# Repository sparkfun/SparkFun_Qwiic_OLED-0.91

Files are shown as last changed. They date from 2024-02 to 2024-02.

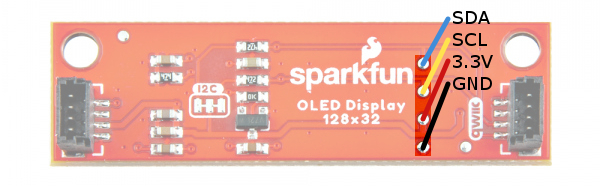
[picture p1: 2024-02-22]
docs/assets/img/LCD-24606-Qwiic-OLED-Display-Back_I2C_Test_Points.jpg

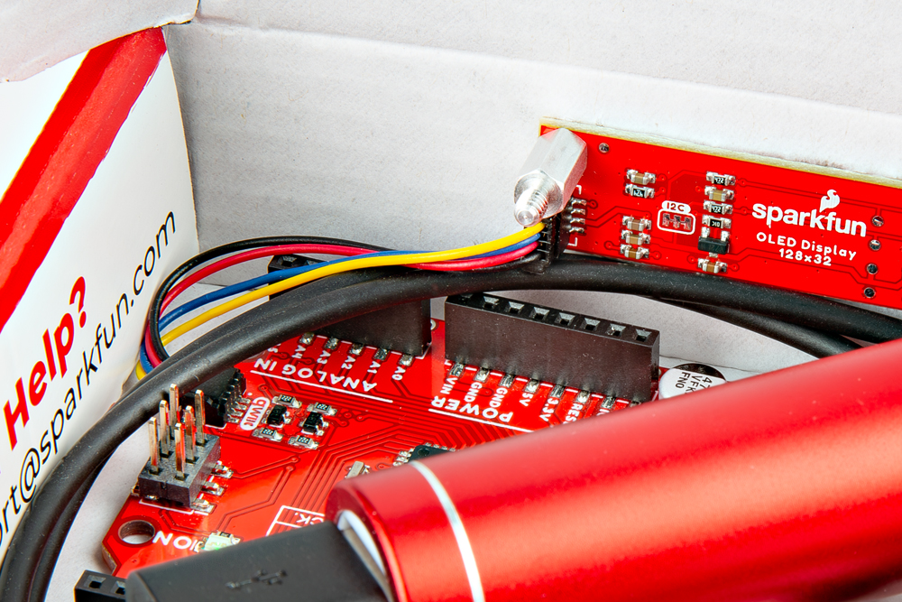
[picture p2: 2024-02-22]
docs/assets/img/LCD-24606-Qwiic-OLED-Display_Enclosure_Qwiic_Cable.jpg

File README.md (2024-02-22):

SparkFun Qwiic OLED Display (0.91", 128x32)
========================================

SparkFun Qwiic OLED Display (0.91", 128x32) (https://www.sparkfun.com/products/24606)

[*SparkFun Qwiic OLED Display (0.91", 128x32) [LCD-24606]*](https://www.sparkfun.com/products/24606)

The SparkFun Qwiic OLED Display can display up to three lines of text and features 128x32 pixels in a small 0.91” (diagonal) frame. As an OLED, this display does not have a back light layer (unlike LCDs) and therefore it’s thinner, consumes less power, and has higher contrast. 

Thanks to an I<sup>2</sup>C command structure, the board's firmware maintains speed by updating only the part of the screen that changes. This is the same concept use with "Dirty Rectangles" or "Bit blit" operations in computer graphics. 

Version 1.1 of the Qwiic OLED display includes 2x vertical Qwiic connectors populated on the back of the board to easily mount the board and keep the wires inside of the enclosure. Note that the two mounting holes have also been moved to one side of the board. 

Repository Contents
-------------------

* **/Hardware** - Eagle design files (.brd, .sch)
* **/Production** - Production panel files (.brd)

Documentation
--------------
* **[Library](https://docs.sparkfun.com/SparkFun_Qwiic_OLED_Arduino_Library/)** - Arduino library for the Qwiic OLED Display (0.91", 128x32).
* **[Hookup Guide](https://docs.sparkfun.com/SparkFun_Qwiic_OLED_Arduino_Library/)** - Basic hookup guide for the Qwiic OLED Display (0.91", 128x32).

Product Versions
----------------
* [LCD-24606](https://www.sparkfun.com/products/24606) - Initial release, v1.1

Version History
---------------
* v1.1 - Initial release

License Information
-------------------

This product is _**open source**_! 

Please review the LICENSE.md file for license information. 

If you have any questions or concerns on licensing, please contact technical support on our [SparkFun forums](https://forum.sparkfun.com/viewforum.php?f=152).

Distributed as-is; no warranty is given.

- Your friends at SparkFun.

_<COLLABORATION CREDIT>_

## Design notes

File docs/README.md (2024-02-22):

The files contained in these folders are used for the product page and [SparkFun Qwiic OLED Arduino Library - Hookup Guide](https://docs.sparkfun.com/SparkFun_Qwiic_OLED_Arduino_Library/). Be careful about deleting the files or changing the paths for the Qwiic OLED (0.1", 128x32).

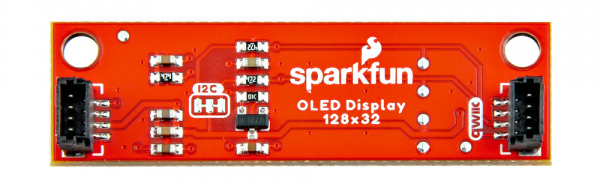
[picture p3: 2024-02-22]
docs/assets/img/LCD-24606-Qwiic-OLED-Display_bottom.jpg

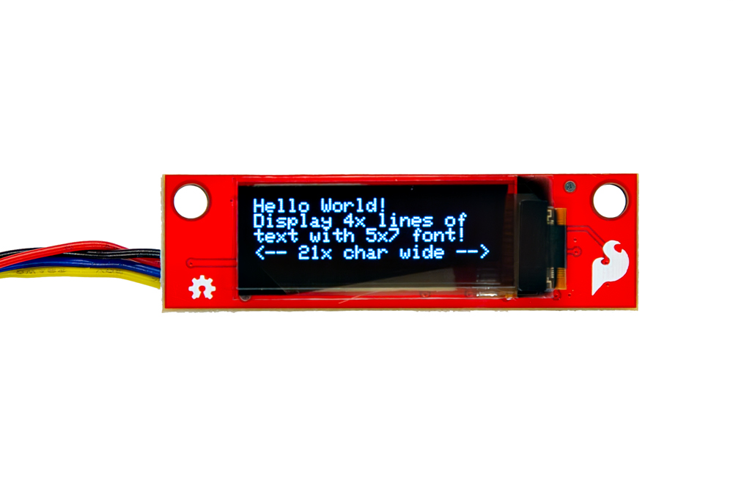
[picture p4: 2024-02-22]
docs/assets/img/LCD-24606-Qwiic-OLED-Display-Action_Text_5x7_Font.jpg

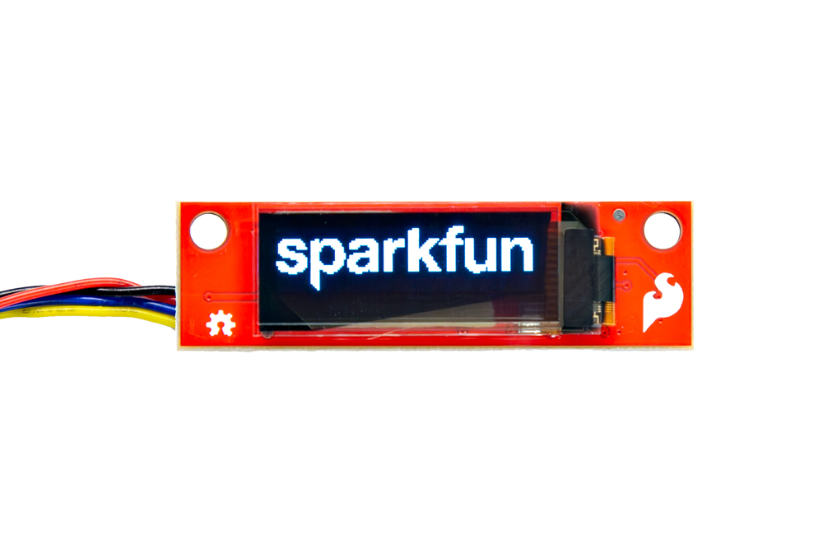
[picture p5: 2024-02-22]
docs/assets/img/LCD-24606-Qwiic-OLED-Display-Action_Bitmap.jpg

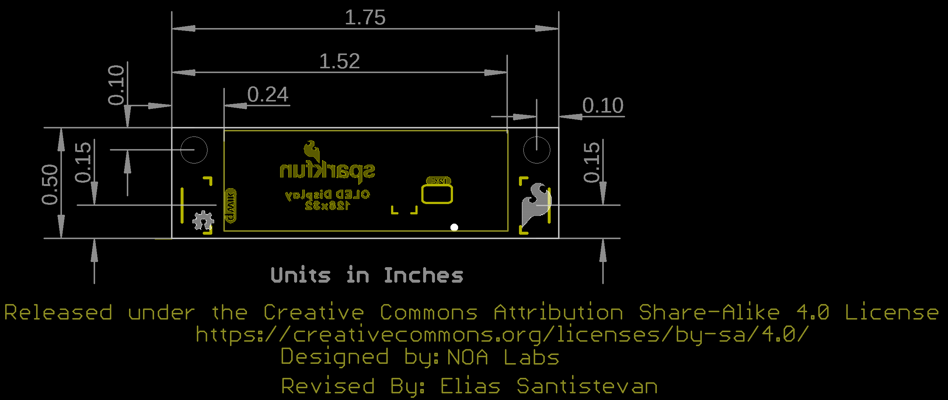
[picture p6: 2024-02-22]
docs/assets/img/SparkFun_Qwiic_OLED-0p9in_Board_Dimensions.png

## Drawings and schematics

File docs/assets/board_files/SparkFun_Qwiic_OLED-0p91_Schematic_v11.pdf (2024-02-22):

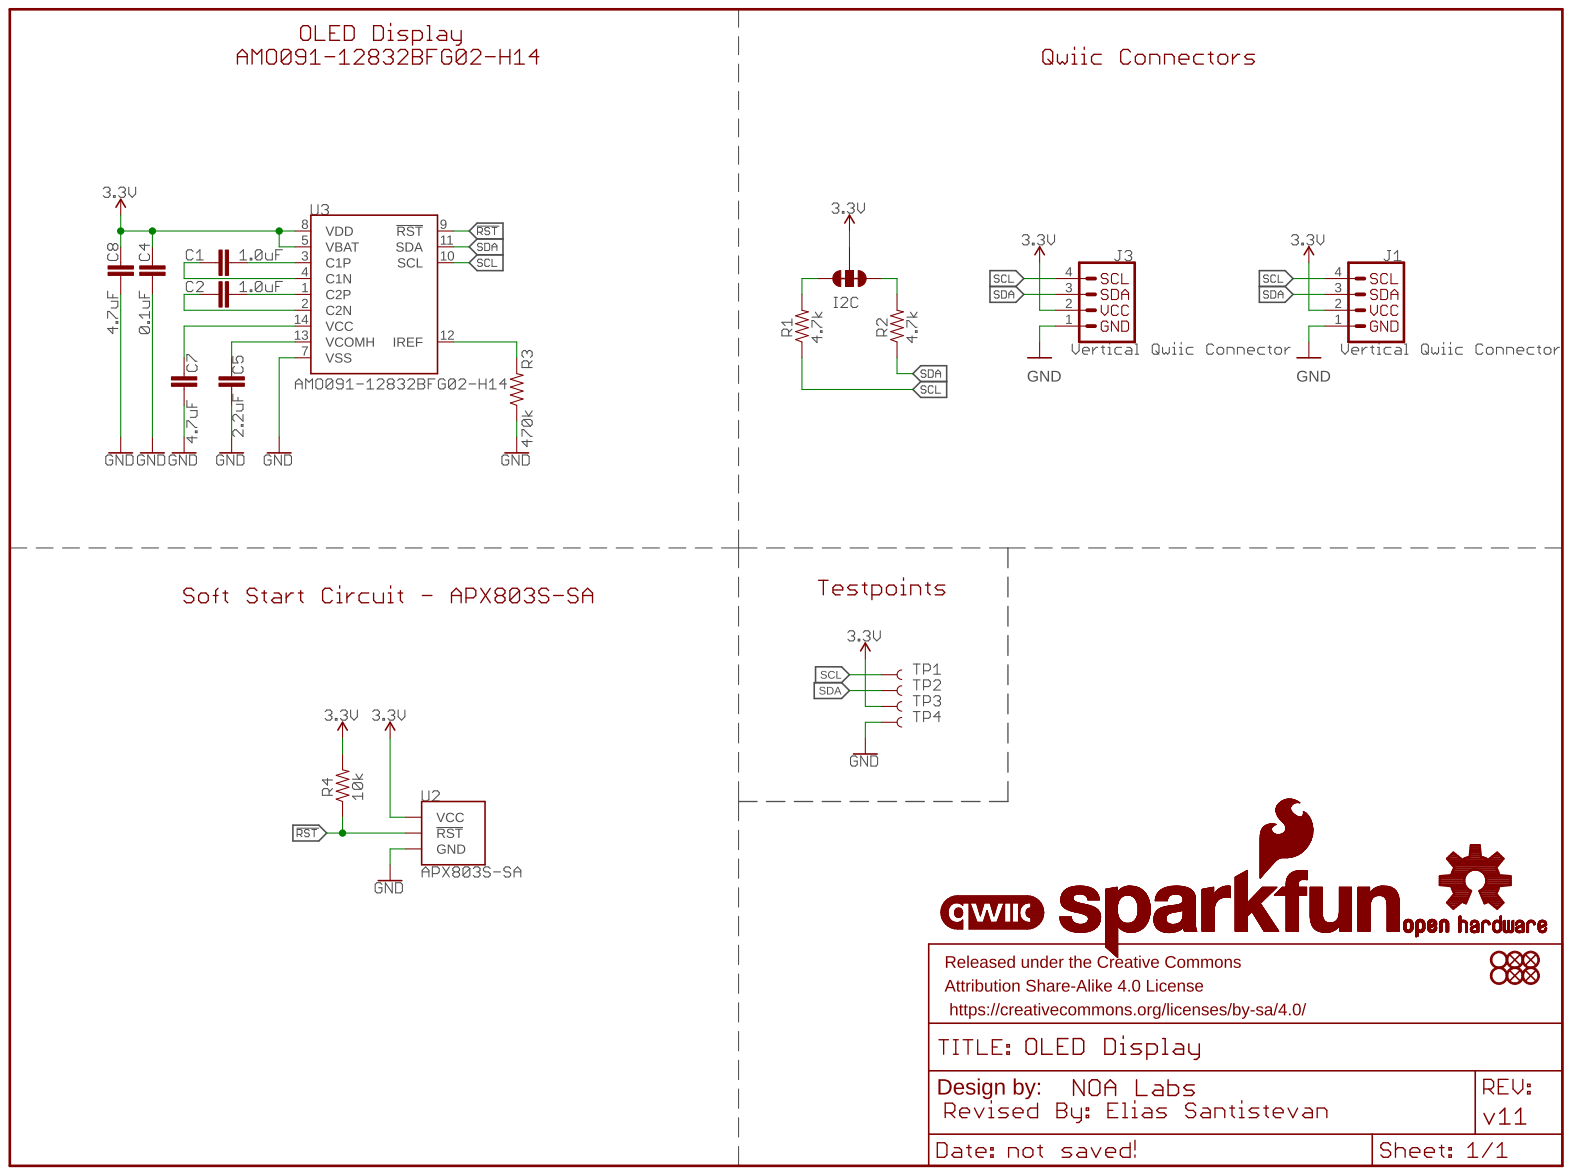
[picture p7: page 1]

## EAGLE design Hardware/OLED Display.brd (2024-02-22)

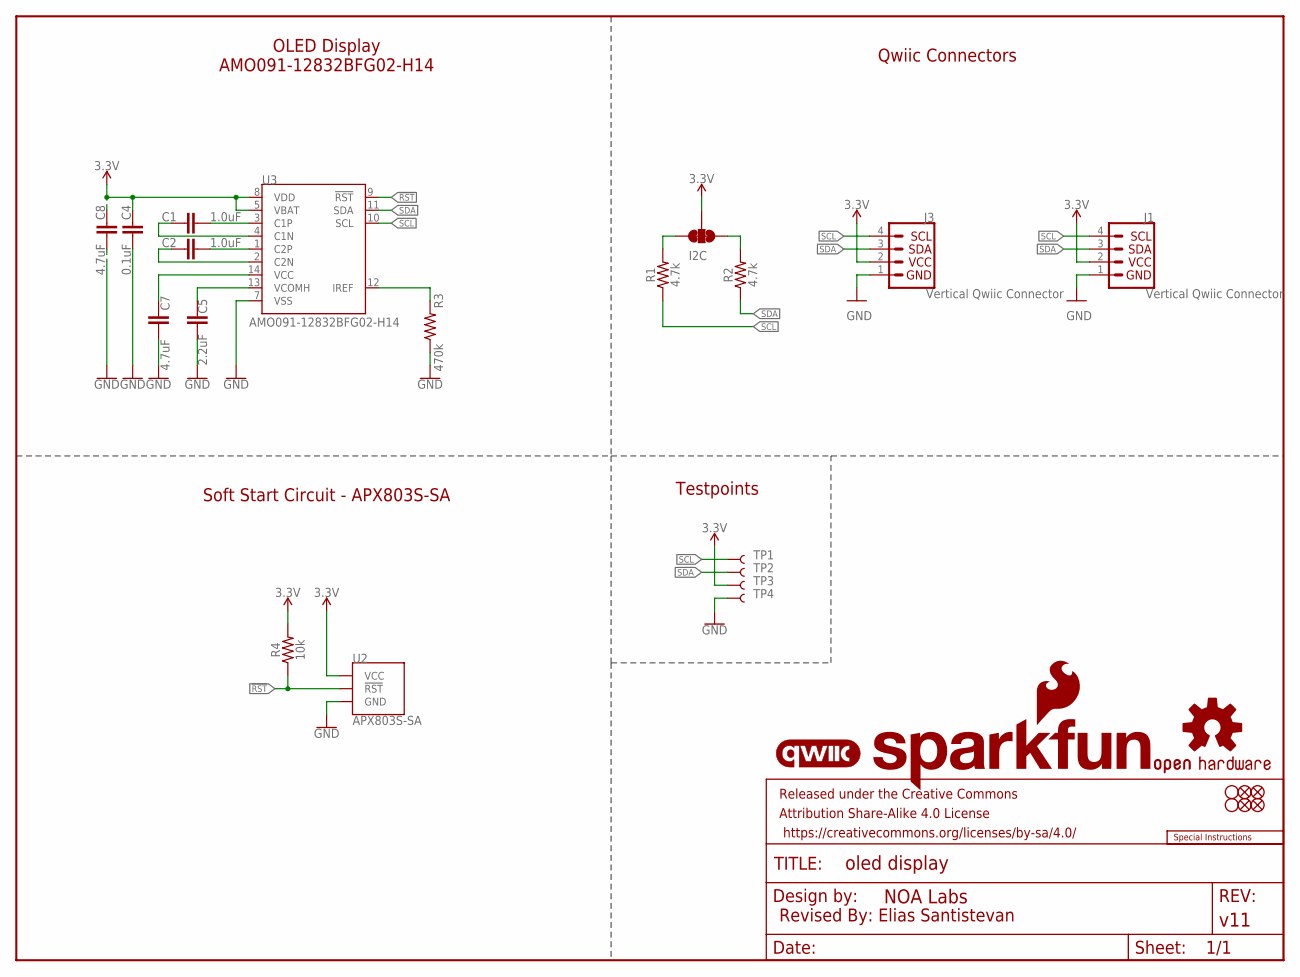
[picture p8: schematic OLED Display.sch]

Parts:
C1, C2: 1.0uF; 0603
C4: 0.1uF; 0603
C5: 2.2uF; 0603
C7, C8: 4.7uF; 0603
FD1, FD2, FD3, FD4: FIDUCIAL1X2; FIDUCIAL-1X2
FRAME2: FRAME-LETTER; CREATIVE_COMMONS
H1, H2: STAND-OFFTIGHT; STAND-OFF-TIGHT
I2C: JUMPER-SMT_3_2-NC_TRACE_SILK; SMT-JUMPER_3_2-NC_TRACE_SILK
J1, J3: Vertical Qwiic Connector; JST04_1MM_VERT
LOGO1: SFE_LOGO_NAME_FLAME.1_INCH; SFE_LOGO_NAME_FLAME_.1
LOGO2: OSHW-LOGOMINI; OSHW-LOGO-MINI
LOGO3: QWIIC_LOGO_4MM; QWIIC_4MM
LOGO4: SPECIAL_INSTRUCTIONS-ORDERING; ORDERING_INSTRUCTIONS
R1, R2: 4.7k; 0603
R3: 470k; 0603
R4: 10k; 0603
TP1, TP2, TP3, TP4: TEST-POINT3X4; PAD.03X.04
U2: APX803S-SA; SOT23-3
U3: AMO091-12832BFG02-H14

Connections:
3.3V: C4.1, C8.2, I2C.2, J1.2, J3.2, R4.2, TP3.1, U2.3 (VCC), U3.5 (VBAT), U3.8 (VDD)
!RST!: R4.1, U2.2 (!RST!), U3.9 (!RST!)
GND: C4.2, C5.2, C7.1, C8.1, J1.1, J3.1, R3.1, TP4.1, U2.1 (GND), U3.7 (VSS)
unnamed: C2.2, U3.1 (C2P)
unnamed: C1.1, U3.4 (C1N)
unnamed: C1.2, U3.3 (C1P)
unnamed: I2C.3, R1.2
unnamed: C5.1, U3.13 (VCOMH)
unnamed: C7.2, U3.14 (VCC)
unnamed: I2C.1, R2.2
unnamed: R3.2, U3.12 (IREF)
unnamed: C2.1, U3.2 (C2N)
SCL: J1.4, J3.4, R1.1, TP1.1, U3.10 (SCL)
SDA: J1.3, J3.3, R2.1, TP2.1, U3.11 (SDA)

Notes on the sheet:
Revised By: Elias Santistevan
Qwiic Connectors
OLED Display AMO091-12832BFG02-H14
Soft Start Circuit - APX803S-SA
Testpoints

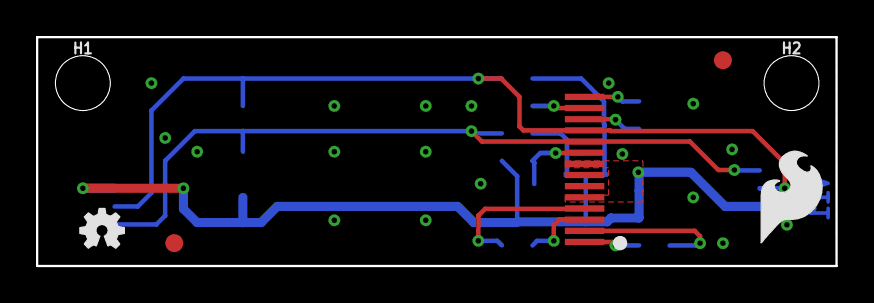
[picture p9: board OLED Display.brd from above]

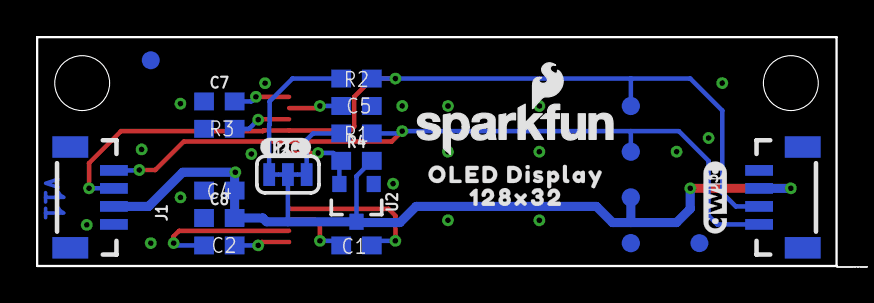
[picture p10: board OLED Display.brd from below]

Board: 2 copper layers, 44.4 x 12.7 mm, 34 parts (25 on the bottom side), 14 nets.

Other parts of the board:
U$1: SFE_LOGO_FLAME_.2
U$2: OLED_DISPLAY94
U$3: 128X3295
U$4: #I2C#16

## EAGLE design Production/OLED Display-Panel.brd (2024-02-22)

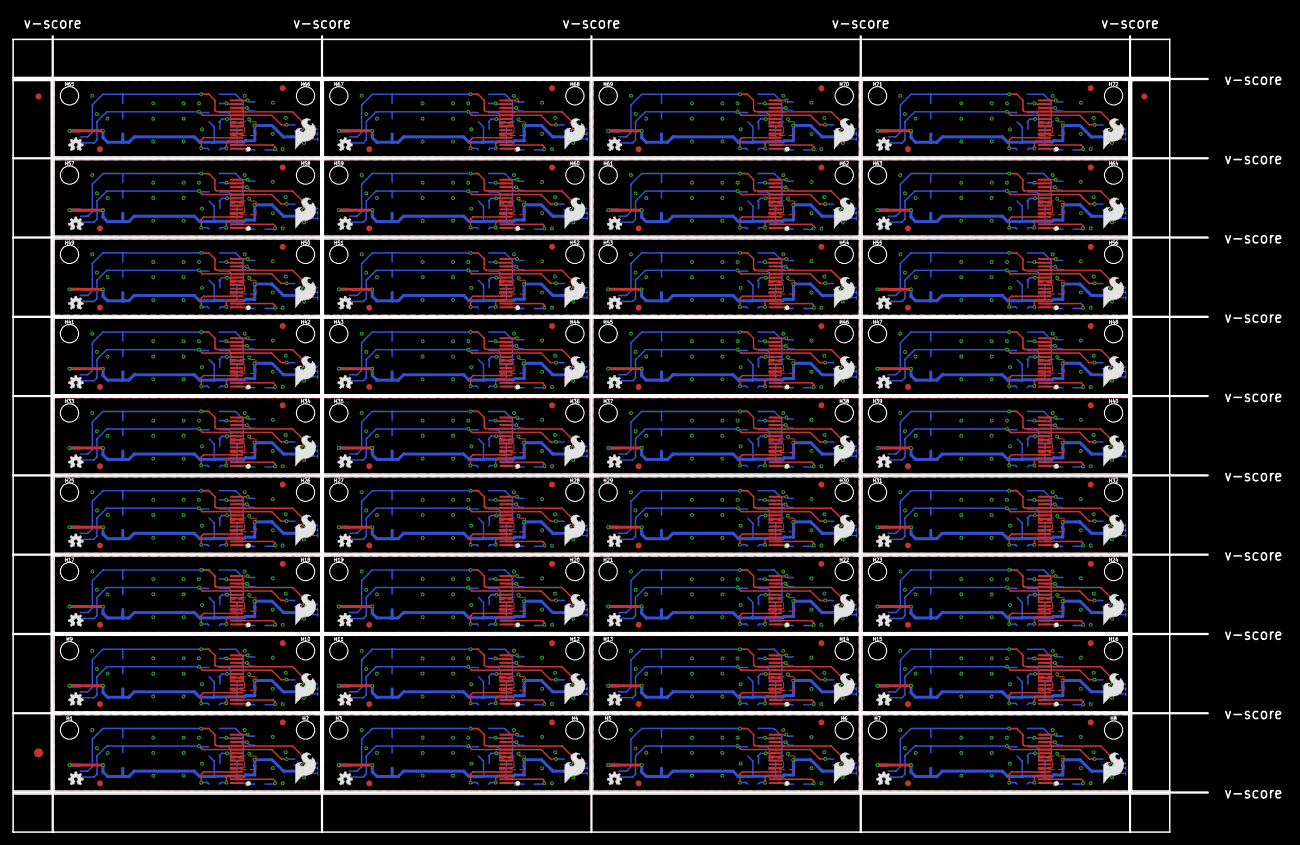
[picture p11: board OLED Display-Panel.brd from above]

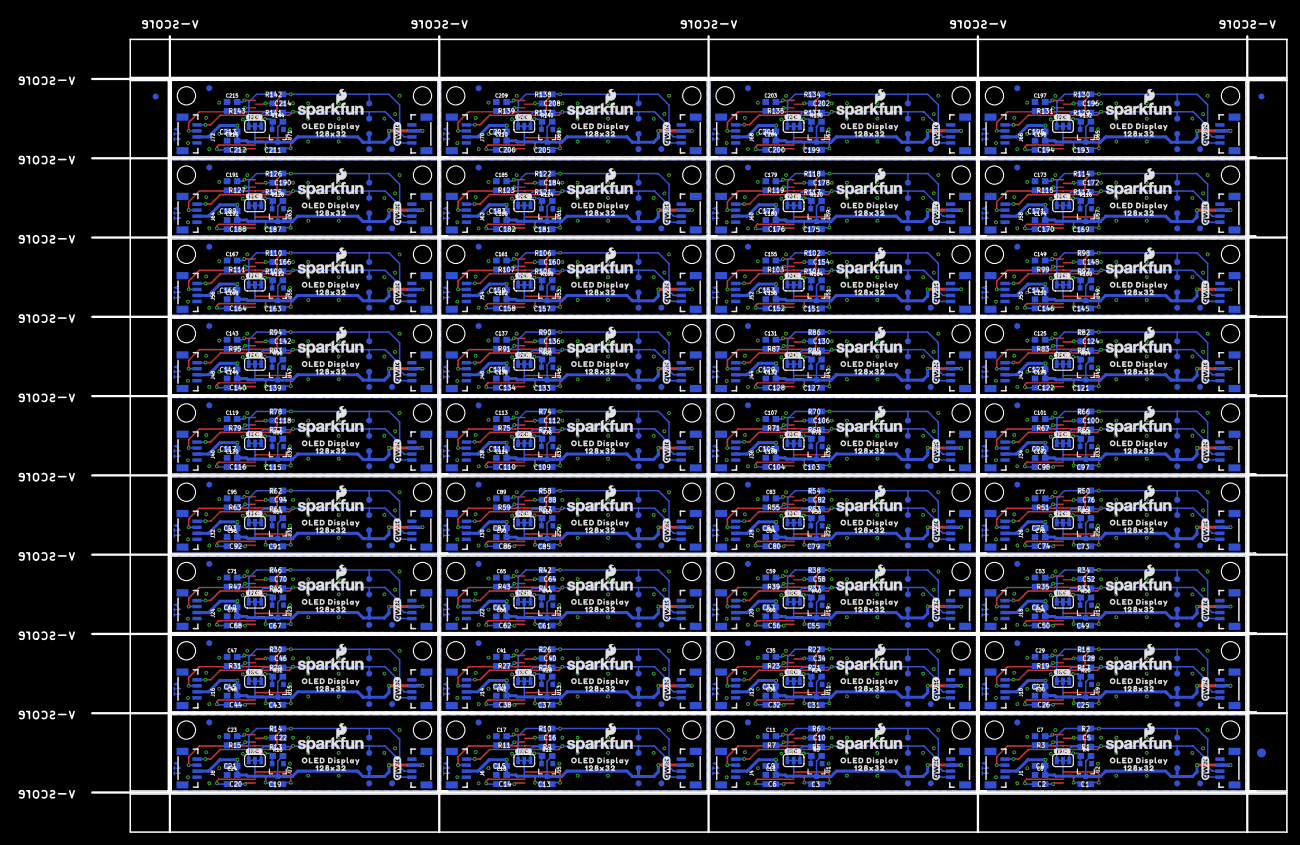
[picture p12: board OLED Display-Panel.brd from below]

Board: 2 copper layers, 199.2 x 132.7 mm, 1158 parts (903 on the bottom side), 504 nets.

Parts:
C1, C2, C3, C6, C13, C14, C19, C20, C25, C26, C31, C32, C37, C38, C43, C44, C49, C50, C55, C56, C61, C62, C67, C68, C73, C74, C79, C80, C85, C86, C91, C92, C97, C98, C103, C104, C109, C110, C115, C116, C121, C122, C127, C128, C133, C134, C139, C140, C145, C146, C151, C152, C157, C158, C163, C164, C169, C170, C175, C176, C181, C182, C187, C188, C193, C194, C199, C200, C205, C206, C211, C212: 1.0uF; 0603
C4, C9, C15, C21, C27, C33, C39, C45, C51, C57, C63, C69, C75, C81, C87, C93, C99, C105, C111, C117, C123, C129, C135, C141, C147, C153, C159, C165, C171, C177, C183, C189, C195, C201, C207, C213: 0.1uF; 0603
C5, C10, C16, C22, C28, C34, C40, C46, C52, C58, C64, C70, C76, C82, C88, C94, C100, C106, C112, C118, C124, C130, C136, C142, C148, C154, C160, C166, C172, C178, C184, C190, C196, C202, C208, C214: 2.2uF; 0603
C7, C8, C11, C12, C17, C18, C23, C24, C29, C30, C35, C36, C41, C42, C47, C48, C53, C54, C59, C60, C65, C66, C71, C72, C77, C78, C83, C84, C89, C90, C95, C96, C101, C102, C107, C108, C113, C114, C119, C120, C125, C126, C131, C132, C137, C138, C143, C144, C149, C150, C155, C156, C161, C162, C167, C168, C173, C174, C179, C180, C185, C186, C191, C192, C197, C198, C203, C204, C209, C210, C215, C216: 4.7uF; 0603
E$1, E$2, E$3, E$4: FIDUCIAL-1X2
E$5, E$6: FIDUCIAL-1.5X3
FD1, FD2, FD3, FD4, FD5, FD6, FD7, FD8, FD9, FD10, FD11, FD12, FD13, FD14, FD15, FD16, FD17, FD18, FD19, FD20, FD21, FD22, FD23, FD24, FD25, FD26, FD27, FD28, FD29, FD30, FD31, FD32, FD33, FD34, FD35, FD36, FD37, FD38, FD39, FD40, FD41, FD42, FD43, FD44, FD45, FD46, FD47, FD48, FD49, FD50, FD51, FD52, FD53, FD54, FD55, FD56, FD57, FD58, FD59, FD60, FD61, FD62, FD63, FD64, FD65, FD66, FD67, FD68, FD69, FD70, FD71, FD72, FD73, FD74, FD75, FD76, FD77, FD78, FD79, FD80, FD81, FD82, FD83, FD84, FD85, FD86, FD87, FD88, FD89, FD90, FD91, FD92, FD93, FD94, FD95, FD96, FD97, FD98, FD99, FD100, FD101, FD102, FD103, FD104, FD105, FD106, FD107, FD108, FD109, FD110, FD111, FD112, FD113, FD114, FD115, FD116, FD117, FD118, FD119, FD120, FD121, FD122, FD123, FD124, FD125, FD126, FD127, FD128, FD129, FD130, FD131, FD132, FD133, FD134, FD135, FD136, FD137, FD138, FD139, FD140, FD141, FD142, FD143, FD144: FIDUCIAL1X2; FIDUCIAL-1X2
H1, H2, H3, H4, H5, H6, H7, H8, H9, H10, H11, H12, H13, H14, H15, H16, H17, H18, H19, H20, H21, H22, H23, H24, H25, H26, H27, H28, H29, H30, H31, H32, H33, H34, H35, H36, H37, H38, H39, H40, H41, H42, H43, H44, H45, H46, H47, H48, H49, H50, H51, H52, H53, H54, H55, H56, H57, H58, H59, H60, H61, H62, H63, H64, H65, H66, H67, H68, H69, H70, H71, H72: STAND-OFFTIGHT; STAND-OFF-TIGHT
I2C, I2C1, I2C2, I2C3, I2C4, I2C5, I2C6, I2C7, I2C8, I2C9, I2C10, I2C11, I2C12, I2C13, I2C14, I2C15, I2C16, I2C17, I2C18, I2C19, I2C20, I2C21, I2C22, I2C23, I2C24, I2C25, I2C26, I2C27, I2C28, I2C29, I2C30, I2C31, I2C32, I2C33, I2C34, I2C35: JUMPER-SMT_3_2-NC_TRACE_SILK; SMT-JUMPER_3_2-NC_TRACE_SILK
J1, J2, J3, J4, J5, J6, J7, J8, J9, J10, J11, J12, J13, J14, J15, J16, J17, J18, J19, J20, J21, J22, J23, J24, J25, J26, J27, J28, J29, J30, J31, J32, J33, J34, J35, J36, J37, J38, J39, J40, J41, J42, J43, J44, J45, J46, J47, J48, J49, J50, J51, J52, J53, J54, J55, J56, J57, J58, J59, J60, J61, J62, J63, J64, J65, J66, J67, J68, J69, J70, J71, J72: Vertical Qwiic Connector; JST04_1MM_VERT
LOGO1, LOGO6, LOGO9, LOGO12, LOGO15, LOGO18, LOGO21, LOGO24, LOGO27, LOGO30, LOGO33, LOGO36, LOGO39, LOGO42, LOGO45, LOGO48, LOGO51, LOGO54, LOGO57, LOGO60, LOGO63, LOGO66, LOGO69, LOGO72, LOGO75, LOGO78, LOGO81, LOGO84, LOGO87, LOGO90, LOGO93, LOGO96, LOGO99, LOGO102, LOGO105, LOGO108: SFE_LOGO_NAME_FLAME.1_INCH; SFE_LOGO_NAME_FLAME_.1
LOGO2, LOGO4, LOGO7, LOGO10, LOGO13, LOGO16, LOGO19, LOGO22, LOGO25, LOGO28, LOGO31, LOGO34, LOGO37, LOGO40, LOGO43, LOGO46, LOGO49, LOGO52, LOGO55, LOGO58, LOGO61, LOGO64, LOGO67, LOGO70, LOGO73, LOGO76, LOGO79, LOGO82, LOGO85, LOGO88, LOGO91, LOGO94, LOGO97, LOGO100, LOGO103, LOGO106: OSHW-LOGOMINI; OSHW-LOGO-MINI
LOGO3, LOGO5, LOGO8, LOGO11, LOGO14, LOGO17, LOGO20, LOGO23, LOGO26, LOGO29, LOGO32, LOGO35, LOGO38, LOGO41, LOGO44, LOGO47, LOGO50, LOGO53, LOGO56, LOGO59, LOGO62, LOGO65, LOGO68, LOGO71, LOGO74, LOGO77, LOGO80, LOGO83, LOGO86, LOGO89, LOGO92, LOGO95, LOGO98, LOGO101, LOGO104, LOGO107: QWIIC_LOGO_4MM; QWIIC_4MM
R1, R2, R5, R6, R9, R10, R13, R14, R17, R18, R21, R22, R25, R26, R29, R30, R33, R34, R37, R38, R41, R42, R45, R46, R49, R50, R53, R54, R57, R58, R61, R62, R65, R66, R69, R70, R73, R74, R77, R78, R81, R82, R85, R86, R89, R90, R93, R94, R97, R98, R101, R102, R105, R106, R109, R110, R113, R114, R117, R118, R121, R122, R125, R126, R129, R130, R133, R134, R137, R138, R141, R142: 4.7k; 0603
R3, R7, R11, R15, R19, R23, R27, R31, R35, R39, R43, R47, R51, R55, R59, R63, R67, R71, R75, R79, R83, R87, R91, R95, R99, R103, R107, R111, R115, R119, R123, R127, R131, R135, R139, R143: 470k; 0603
R4, R8, R12, R16, R20, R24, R28, R32, R36, R40, R44, R48, R52, R56, R60, R64, R68, R72, R76, R80, R84, R88, R92, R96, R100, R104, R108, R112, R116, R120, R124, R128, R132, R136, R140, R144: 10k; 0603
TP1, TP2, TP3, TP4, TP5, TP6, TP7, TP8, TP9, TP10, TP11, TP12, TP13, TP14, TP15, TP16, TP17, TP18, TP19, TP20, TP21, TP22, TP23, TP24, TP25, TP26, TP27, TP28, TP29, TP30, TP31, TP32, TP33, TP34, TP35, TP36, TP37, TP38, TP39, TP40, TP41, TP42, TP43, TP44, TP45, TP46, TP47, TP48, TP49, TP50, TP51, TP52, TP53, TP54, TP55, TP56, TP57, TP58, TP59, TP60, TP61, TP62, TP63, TP64, TP65, TP66, TP67, TP68, TP69, TP70, TP71, TP72, TP73, TP74, TP75, TP76, TP77, TP78, TP79, TP80, TP81, TP82, TP83, TP84, TP85, TP86, TP87, TP88, TP89, TP90, TP91, TP92, TP93, TP94, TP95, TP96, TP97, TP98, TP99, TP100, TP101, TP102, TP103, TP104, TP105, TP106, TP107, TP108, TP109, TP110, TP111, TP112, TP113, TP114, TP115, TP116, TP117, TP118, TP119, TP120, TP121, TP122, TP123, TP124, TP125, TP126, TP127, TP128, TP129, TP130, TP131, TP132, TP133, TP134, TP135, TP136, TP137, TP138, TP139, TP140, TP141, TP142, TP143, TP144: TEST-POINT3X4; PAD.03X.04
U1, U2, U5, U7, U9, U11, U13, U15, U17, U19, U21, U23, U25, U27, U29, U31, U33, U35, U37, U39, U41, U43, U45, U47, U49, U51, U53, U55, U57, U59, U61, U63, U65, U67, U69, U71: APX803S-SA; SOT23-3
U3, U4, U6, U8, U10, U12, U14, U16, U18, U20, U22, U24, U26, U28, U30, U32, U34, U36, U38, U40, U42, U44, U46, U48, U50, U52, U54, U56, U58, U60, U62, U64, U66, U68, U70, U72: AMO091-12832BFG02-H14
U$1, U$5, U$9, U$13, U$17, U$21, U$25, U$29, U$33, U$37, U$41, U$45, U$49, U$53, U$57, U$61, U$65, U$69, U$73, U$77, U$81, U$85, U$89, U$93, U$97, U$101, U$105, U$109, U$113, U$117, U$121, U$125, U$129, U$133, U$137, U$141: SFE_LOGO_FLAME_.2
U$2, U$6, U$10, U$14, U$18, U$22, U$26, U$30, U$34, U$38, U$42, U$46, U$50, U$54, U$58, U$62, U$66, U$70, U$74, U$78, U$82, U$86, U$90, U$94, U$98, U$102, U$106, U$110, U$114, U$118, U$122, U$126, U$130, U$134, U$138, U$142: OLED_DISPLAY94
U$3, U$7, U$11, U$15, U$19, U$23, U$27, U$31, U$35, U$39, U$43, U$47, U$51, U$55, U$59, U$63, U$67, U$71, U$75, U$79, U$83, U$87, U$91, U$95, U$99, U$103, U$107, U$111, U$115, U$119, U$123, U$127, U$131, U$135, U$139, U$143: 128X3295
U$4, U$8, U$12, U$16, U$20, U$24, U$28, U$32, U$36, U$40, U$44, U$48, U$52, U$56, U$60, U$64, U$68, U$72, U$76, U$80, U$84, U$88, U$92, U$96, U$100, U$104, U$108, U$112, U$116, U$120, U$124, U$128, U$132, U$136, U$140, U$144: #I2C#16

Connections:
3.3V: C4.1, C8.2, I2C.2, J1.2, J3.2, R4.2, TP3.1, U2.3, U3.5, U3.8
3.3V1: C9.1, C12.2, I2C1.2, J2.2, J4.2, R8.2, TP7.1, U1.3, U4.5, U4.8
3.3V2: C15.1, C18.2, I2C2.2, J5.2, J6.2, R12.2, TP11.1, U5.3, U6.5, U6.8
3.3V3: C21.1, C24.2, I2C3.2, J7.2, J8.2, R16.2, TP15.1, U7.3, U8.5, U8.8
3.3V4: C27.1, C30.2, I2C4.2, J9.2, J10.2, R20.2, TP19.1, U9.3, U10.5, U10.8
3.3V5: C33.1, C36.2, I2C5.2, J11.2, J12.2, R24.2, TP23.1, U11.3, U12.5, U12.8
3.3V6: C39.1, C42.2, I2C6.2, J13.2, J14.2, R28.2, TP27.1, U13.3, U14.5, U14.8
3.3V7: C45.1, C48.2, I2C7.2, J15.2, J16.2, R32.2, TP31.1, U15.3, U16.5, U16.8
3.3V8: C51.1, C54.2, I2C8.2, J17.2, J18.2, R36.2, TP35.1, U17.3, U18.5, U18.8
3.3V9: C57.1, C60.2, I2C9.2, J19.2, J20.2, R40.2, TP39.1, U19.3, U20.5, U20.8
3.3V10: C63.1, C66.2, I2C10.2, J21.2, J22.2, R44.2, TP43.1, U21.3, U22.5, U22.8
3.3V11: C69.1, C72.2, I2C11.2, J23.2, J24.2, R48.2, TP47.1, U23.3, U24.5, U24.8
3.3V12: C75.1, C78.2, I2C12.2, J25.2, J26.2, R52.2, TP51.1, U25.3, U26.5, U26.8
3.3V13: C81.1, C84.2, I2C13.2, J27.2, J28.2, R56.2, TP55.1, U27.3, U28.5, U28.8
3.3V14: C87.1, C90.2, I2C14.2, J29.2, J30.2, R60.2, TP59.1, U29.3, U30.5, U30.8
3.3V15: C93.1, C96.2, I2C15.2, J31.2, J32.2, R64.2, TP63.1, U31.3, U32.5, U32.8
3.3V16: C99.1, C102.2, I2C16.2, J33.2, J34.2, R68.2, TP67.1, U33.3, U34.5, U34.8
3.3V17: C105.1, C108.2, I2C17.2, J35.2, J36.2, R72.2, TP71.1, U35.3, U36.5, U36.8
3.3V18: C111.1, C114.2, I2C18.2, J37.2, J38.2, R76.2, TP75.1, U37.3, U38.5, U38.8
3.3V19: C117.1, C120.2, I2C19.2, J39.2, J40.2, R80.2, TP79.1, U39.3, U40.5, U40.8
3.3V20: C123.1, C126.2, I2C20.2, J41.2, J42.2, R84.2, TP83.1, U41.3, U42.5, U42.8
3.3V21: C129.1, C132.2, I2C21.2, J43.2, J44.2, R88.2, TP87.1, U43.3, U44.5, U44.8
3.3V22: C135.1, C138.2, I2C22.2, J45.2, J46.2, R92.2, TP91.1, U45.3, U46.5, U46.8
3.3V23: C141.1, C144.2, I2C23.2, J47.2, J48.2, R96.2, TP95.1, U47.3, U48.5, U48.8
3.3V24: C147.1, C150.2, I2C24.2, J49.2, J50.2, R100.2, TP99.1, U49.3, U50.5, U50.8
3.3V25: C153.1, C156.2, I2C25.2, J51.2, J52.2, R104.2, TP103.1, U51.3, U52.5, U52.8
3.3V26: C159.1, C162.2, I2C26.2, J53.2, J54.2, R108.2, TP107.1, U53.3, U54.5, U54.8
3.3V27: C165.1, C168.2, I2C27.2, J55.2, J56.2, R112.2, TP111.1, U55.3, U56.5, U56.8
3.3V28: C171.1, C174.2, I2C28.2, J57.2, J58.2, R116.2, TP115.1, U57.3, U58.5, U58.8
3.3V29: C177.1, C180.2, I2C29.2, J59.2, J60.2, R120.2, TP119.1, U59.3, U60.5, U60.8
3.3V30: C183.1, C186.2, I2C30.2, J61.2, J62.2, R124.2, TP123.1, U61.3, U62.5, U62.8
3.3V31: C189.1, C192.2, I2C31.2, J63.2, J64.2, R128.2, TP127.1, U63.3, U64.5, U64.8
3.3V32: C195.1, C198.2, I2C32.2, J65.2, J66.2, R132.2, TP131.1, U65.3, U66.5, U66.8
3.3V33: C201.1, C204.2, I2C33.2, J67.2, J68.2, R136.2, TP135.1, U67.3, U68.5, U68.8
3.3V34: C207.1, C210.2, I2C34.2, J69.2, J70.2, R140.2, TP139.1, U69.3, U70.5, U70.8
3.3V35: C213.1, C216.2, I2C35.2, J71.2, J72.2, R144.2, TP143.1, U71.3, U72.5, U72.8
!RST!: R4.1, U2.2, U3.9
!RST!1: R8.1, U1.2, U4.9
!RST!2: R12.1, U5.2, U6.9
!RST!3: R16.1, U7.2, U8.9
!RST!4: R20.1, U9.2, U10.9
!RST!5: R24.1, U11.2, U12.9
!RST!6: R28.1, U13.2, U14.9
!RST!7: R32.1, U15.2, U16.9
!RST!8: R36.1, U17.2, U18.9
!RST!9: R40.1, U19.2, U20.9
!RST!10: R44.1, U21.2, U22.9
!RST!11: R48.1, U23.2, U24.9
!RST!12: R52.1, U25.2, U26.9
!RST!13: R56.1, U27.2, U28.9
!RST!14: R60.1, U29.2, U30.9
!RST!15: R64.1, U31.2, U32.9
!RST!16: R68.1, U33.2, U34.9
!RST!17: R72.1, U35.2, U36.9
!RST!18: R76.1, U37.2, U38.9
!RST!19: R80.1, U39.2, U40.9
!RST!20: R84.1, U41.2, U42.9
!RST!21: R88.1, U43.2, U44.9
!RST!22: R92.1, U45.2, U46.9
!RST!23: R96.1, U47.2, U48.9
!RST!24: R100.1, U49.2, U50.9
!RST!25: R104.1, U51.2, U52.9
!RST!26: R108.1, U53.2, U54.9
!RST!27: R112.1, U55.2, U56.9
!RST!28: R116.1, U57.2, U58.9
!RST!29: R120.1, U59.2, U60.9
!RST!30: R124.1, U61.2, U62.9
!RST!31: R128.1, U63.2, U64.9
!RST!32: R132.1, U65.2, U66.9
!RST!33: R136.1, U67.2, U68.9
!RST!34: R140.1, U69.2, U70.9
!RST!35: R144.1, U71.2, U72.9
GND: C4.2, C5.2, C7.1, C8.1, J1.1, J3.1, R3.1, TP4.1, U2.1, U3.7
GND1: C9.2, C10.2, C11.1, C12.1, J2.1, J4.1, R7.1, TP8.1, U1.1, U4.7
GND2: C15.2, C16.2, C17.1, C18.1, J5.1, J6.1, R11.1, TP12.1, U5.1, U6.7
GND3: C21.2, C22.2, C23.1, C24.1, J7.1, J8.1, R15.1, TP16.1, U7.1, U8.7
GND4: C27.2, C28.2, C29.1, C30.1, J9.1, J10.1, R19.1, TP20.1, U9.1, U10.7
GND5: C33.2, C34.2, C35.1, C36.1, J11.1, J12.1, R23.1, TP24.1, U11.1, U12.7
GND6: C39.2, C40.2, C41.1, C42.1, J13.1, J14.1, R27.1, TP28.1, U13.1, U14.7
GND7: C45.2, C46.2, C47.1, C48.1, J15.1, J16.1, R31.1, TP32.1, U15.1, U16.7
GND8: C51.2, C52.2, C53.1, C54.1, J17.1, J18.1, R35.1, TP36.1, U17.1, U18.7
GND9: C57.2, C58.2, C59.1, C60.1, J19.1, J20.1, R39.1, TP40.1, U19.1, U20.7
GND10: C63.2, C64.2, C65.1, C66.1, J21.1, J22.1, R43.1, TP44.1, U21.1, U22.7
GND11: C69.2, C70.2, C71.1, C72.1, J23.1, J24.1, R47.1, TP48.1, U23.1, U24.7
GND12: C75.2, C76.2, C77.1, C78.1, J25.1, J26.1, R51.1, TP52.1, U25.1, U26.7
GND13: C81.2, C82.2, C83.1, C84.1, J27.1, J28.1, R55.1, TP56.1, U27.1, U28.7
GND14: C87.2, C88.2, C89.1, C90.1, J29.1, J30.1, R59.1, TP60.1, U29.1, U30.7
GND15: C93.2, C94.2, C95.1, C96.1, J31.1, J32.1, R63.1, TP64.1, U31.1, U32.7
GND16: C99.2, C100.2, C101.1, C102.1, J33.1, J34.1, R67.1, TP68.1, U33.1, U34.7
GND17: C105.2, C106.2, C107.1, C108.1, J35.1, J36.1, R71.1, TP72.1, U35.1, U36.7
GND18: C111.2, C112.2, C113.1, C114.1, J37.1, J38.1, R75.1, TP76.1, U37.1, U38.7
GND19: C117.2, C118.2, C119.1, C120.1, J39.1, J40.1, R79.1, TP80.1, U39.1, U40.7
GND20: C123.2, C124.2, C125.1, C126.1, J41.1, J42.1, R83.1, TP84.1, U41.1, U42.7
GND21: C129.2, C130.2, C131.1, C132.1, J43.1, J44.1, R87.1, TP88.1, U43.1, U44.7
GND22: C135.2, C136.2, C137.1, C138.1, J45.1, J46.1, R91.1, TP92.1, U45.1, U46.7
GND23: C141.2, C142.2, C143.1, C144.1, J47.1, J48.1, R95.1, TP96.1, U47.1, U48.7
GND24: C147.2, C148.2, C149.1, C150.1, J49.1, J50.1, R99.1, TP100.1, U49.1, U50.7
GND25: C153.2, C154.2, C155.1, C156.1, J51.1, J52.1, R103.1, TP104.1, U51.1, U52.7
GND26: C159.2, C160.2, C161.1, C162.1, J53.1, J54.1, R107.1, TP108.1, U53.1, U54.7
GND27: C165.2, C166.2, C167.1, C168.1, J55.1, J56.1, R111.1, TP112.1, U55.1, U56.7
GND28: C171.2, C172.2, C173.1, C174.1, J57.1, J58.1, R115.1, TP116.1, U57.1, U58.7
GND29: C177.2, C178.2, C179.1, C180.1, J59.1, J60.1, R119.1, TP120.1, U59.1, U60.7
GND30: C183.2, C184.2, C185.1, C186.1, J61.1, J62.1, R123.1, TP124.1, U61.1, U62.7
GND31: C189.2, C190.2, C191.1, C192.1, J63.1, J64.1, R127.1, TP128.1, U63.1, U64.7
GND32: C195.2, C196.2, C197.1, C198.1, J65.1, J66.1, R131.1, TP132.1, U65.1, U66.7
GND33: C201.2, C202.2, C203.1, C204.1, J67.1, J68.1, R135.1, TP136.1, U67.1, U68.7
GND34: C207.2, C208.2, C209.1, C210.1, J69.1, J70.1, R139.1, TP140.1, U69.1, U70.7
GND35: C213.2, C214.2, C215.1, C216.1, J71.1, J72.1, R143.1, TP144.1, U71.1, U72.7
unnamed: C2.2, U3.1
unnamed: C1.1, U3.4
unnamed: C3.1, U4.4
unnamed: C1.2, U3.3
unnamed: I2C.3, R1.2
unnamed: C5.1, U3.13
unnamed: C7.2, U3.14
unnamed: I2C.1, R2.2
unnamed: R3.2, U3.12
unnamed: R7.2, U4.12
unnamed: C10.1, U4.13
unnamed: C11.2, U4.14
unnamed: I2C1.3, R5.2
unnamed: I2C1.1, R6.2
unnamed: C6.2, U4.1
unnamed: C3.2, U4.3
unnamed: C2.1, U3.2
unnamed: C6.1, U4.2
unnamed: C13.1, U6.4
unnamed: R11.2, U6.12
unnamed: C16.1, U6.13
unnamed: C17.2, U6.14
unnamed: I2C2.3, R9.2
unnamed: I2C2.1, R10.2
unnamed: C14.2, U6.1
unnamed: C13.2, U6.3
unnamed: C14.1, U6.2
unnamed: C19.1, U8.4
unnamed: R15.2, U8.12
unnamed: C22.1, U8.13
unnamed: C23.2, U8.14
unnamed: I2C3.3, R13.2
unnamed: I2C3.1, R14.2
unnamed: C20.2, U8.1
unnamed: C19.2, U8.3
unnamed: C20.1, U8.2
unnamed: C25.1, U10.4
unnamed: R19.2, U10.12
unnamed: C28.1, U10.13
unnamed: C29.2, U10.14
unnamed: I2C4.3, R17.2
unnamed: I2C4.1, R18.2
unnamed: C26.2, U10.1
unnamed: C25.2, U10.3
unnamed: C26.1, U10.2
unnamed: C31.1, U12.4
unnamed: R23.2, U12.12
unnamed: C34.1, U12.13
unnamed: C35.2, U12.14
unnamed: I2C5.3, R21.2
unnamed: I2C5.1, R22.2
unnamed: C32.2, U12.1
unnamed: C31.2, U12.3
unnamed: C32.1, U12.2
unnamed: C37.1, U14.4
unnamed: R27.2, U14.12
unnamed: C40.1, U14.13
unnamed: C41.2, U14.14
unnamed: I2C6.3, R25.2
unnamed: I2C6.1, R26.2
unnamed: C38.2, U14.1
unnamed: C37.2, U14.3
unnamed: C38.1, U14.2
unnamed: C43.1, U16.4
unnamed: R31.2, U16.12
unnamed: C46.1, U16.13
unnamed: C47.2, U16.14
unnamed: I2C7.3, R29.2
unnamed: I2C7.1, R30.2
unnamed: C44.2, U16.1
unnamed: C43.2, U16.3
unnamed: C44.1, U16.2
unnamed: C49.1, U18.4
unnamed: R35.2, U18.12
unnamed: C52.1, U18.13
unnamed: C53.2, U18.14
unnamed: I2C8.3, R33.2
unnamed: I2C8.1, R34.2
unnamed: C50.2, U18.1
unnamed: C49.2, U18.3
unnamed: C50.1, U18.2
unnamed: C55.1, U20.4
unnamed: R39.2, U20.12
unnamed: C58.1, U20.13
unnamed: C59.2, U20.14
unnamed: I2C9.3, R37.2
unnamed: I2C9.1, R38.2
unnamed: C56.2, U20.1
unnamed: C55.2, U20.3
unnamed: C56.1, U20.2
unnamed: C61.1, U22.4
unnamed: R43.2, U22.12
unnamed: C64.1, U22.13
unnamed: C65.2, U22.14
unnamed: I2C10.3, R41.2
unnamed: I2C10.1, R42.2
unnamed: C62.2, U22.1
unnamed: C61.2, U22.3
unnamed: C62.1, U22.2
unnamed: C67.1, U24.4
unnamed: R47.2, U24.12
unnamed: C70.1, U24.13
unnamed: C71.2, U24.14
unnamed: I2C11.3, R45.2
unnamed: I2C11.1, R46.2
unnamed: C68.2, U24.1
unnamed: C67.2, U24.3
unnamed: C68.1, U24.2
unnamed: C73.1, U26.4
unnamed: R51.2, U26.12
unnamed: C76.1, U26.13
unnamed: C77.2, U26.14
unnamed: I2C12.3, R49.2
unnamed: I2C12.1, R50.2
unnamed: C74.2, U26.1
unnamed: C73.2, U26.3
unnamed: C74.1, U26.2
unnamed: C79.1, U28.4
unnamed: R55.2, U28.12
unnamed: C82.1, U28.13
unnamed: C83.2, U28.14
unnamed: I2C13.3, R53.2
unnamed: I2C13.1, R54.2
unnamed: C80.2, U28.1
unnamed: C79.2, U28.3
unnamed: C80.1, U28.2
unnamed: C85.1, U30.4
unnamed: R59.2, U30.12
unnamed: C88.1, U30.13
unnamed: C89.2, U30.14
unnamed: I2C14.3, R57.2
unnamed: I2C14.1, R58.2
unnamed: C86.2, U30.1
unnamed: C85.2, U30.3
unnamed: C86.1, U30.2
unnamed: C91.1, U32.4
unnamed: R63.2, U32.12
unnamed: C94.1, U32.13
unnamed: C95.2, U32.14
unnamed: I2C15.3, R61.2
unnamed: I2C15.1, R62.2
unnamed: C92.2, U32.1
unnamed: C91.2, U32.3
unnamed: C92.1, U32.2
unnamed: C97.1, U34.4
unnamed: R67.2, U34.12
unnamed: C100.1, U34.13
unnamed: C101.2, U34.14
unnamed: I2C16.3, R65.2
unnamed: I2C16.1, R66.2
unnamed: C98.2, U34.1
unnamed: C97.2, U34.3
unnamed: C98.1, U34.2
unnamed: C103.1, U36.4
unnamed: R71.2, U36.12
unnamed: C106.1, U36.13
unnamed: C107.2, U36.14
unnamed: I2C17.3, R69.2
unnamed: I2C17.1, R70.2
unnamed: C104.2, U36.1
unnamed: C103.2, U36.3
unnamed: C104.1, U36.2
unnamed: C109.1, U38.4
unnamed: R75.2, U38.12
unnamed: C112.1, U38.13
unnamed: C113.2, U38.14
unnamed: I2C18.3, R73.2
unnamed: I2C18.1, R74.2
unnamed: C110.2, U38.1
unnamed: C109.2, U38.3
unnamed: C110.1, U38.2
unnamed: C115.1, U40.4
unnamed: R79.2, U40.12
unnamed: C118.1, U40.13
unnamed: C119.2, U40.14
unnamed: I2C19.3, R77.2
unnamed: I2C19.1, R78.2
unnamed: C116.2, U40.1
unnamed: C115.2, U40.3
unnamed: C116.1, U40.2
unnamed: C121.1, U42.4
unnamed: R83.2, U42.12
unnamed: C124.1, U42.13
unnamed: C125.2, U42.14
unnamed: I2C20.3, R81.2
unnamed: I2C20.1, R82.2
unnamed: C122.2, U42.1
unnamed: C121.2, U42.3
unnamed: C122.1, U42.2
unnamed: C127.1, U44.4
unnamed: R87.2, U44.12
unnamed: C130.1, U44.13
unnamed: C131.2, U44.14
unnamed: I2C21.3, R85.2
unnamed: I2C21.1, R86.2
unnamed: C128.2, U44.1
unnamed: C127.2, U44.3
unnamed: C128.1, U44.2
unnamed: C133.1, U46.4
unnamed: R91.2, U46.12
unnamed: C136.1, U46.13
unnamed: C137.2, U46.14
unnamed: I2C22.3, R89.2
unnamed: I2C22.1, R90.2
unnamed: C134.2, U46.1
unnamed: C133.2, U46.3
unnamed: C134.1, U46.2
unnamed: C139.1, U48.4
unnamed: R95.2, U48.12
unnamed: C142.1, U48.13
unnamed: C143.2, U48.14
unnamed: I2C23.3, R93.2
unnamed: I2C23.1, R94.2
unnamed: C140.2, U48.1
unnamed: C139.2, U48.3
unnamed: C140.1, U48.2
unnamed: C145.1, U50.4
unnamed: R99.2, U50.12
unnamed: C148.1, U50.13
unnamed: C149.2, U50.14
unnamed: I2C24.3, R97.2
unnamed: I2C24.1, R98.2
unnamed: C146.2, U50.1
unnamed: C145.2, U50.3
unnamed: C146.1, U50.2
unnamed: C151.1, U52.4
unnamed: R103.2, U52.12
unnamed: C154.1, U52.13
unnamed: C155.2, U52.14
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

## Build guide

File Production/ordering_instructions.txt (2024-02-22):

panel size, 193x133mm
PCB thickness, 1.6mm
number of layers, 2
soldermask color, Red
silkscreen color, White
oz copper, 1oz
finish, HASL lead free
stencils, bottom
pcs per panel, 36
min trace width, 0.2540mm / 0.0100in
min drill size, 0.3048mm / 0.0120in

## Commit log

2023-12-08 Uploads Original Design
    [OLED Display.brd, OLED Display.sch]
2023-12-08 Replaces parts not in the SparkFun Eagle Libraries, adds logos, moves qwiic connectors and standoffs
    [OLED Display.brd, OLED Display.sch]
2023-12-08 Replaces more parts
    [OLED Display.brd, OLED Display.sch]
2023-12-08 Changes soft start circuit to RC circuit
    [OLED Display.brd, OLED Display.sch]
2023-12-08 Shrinks the overall size of the board
    [OLED Display.brd, OLED Display.sch]
2023-12-11 Routes the board
    [OLED Display.brd, OLED Display.sch]
2023-12-11 Updates the display device and footprint name, adds version in silk
    [OLED Display.brd, OLED Display.sch]
2023-12-11 Adds label to I2C jumper
    [OLED Display.brd]
2023-12-11 Adds testpoints
    [OLED Display.brd, OLED Display.sch]
2023-12-20 Adds more datasheets, updates part number for OLED display
    [OLED Display.brd, OLED Display.sch]
2023-12-20 Adds more measures
    [OLED Display.brd]
2023-12-20 Adds panel
    [OLED Display-Panel.GBL, OLED Display-Panel.GBP, OLED Display-Panel.GBS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]
2023-12-20 Swaps right angle Qwiic connector to vertical
    [OLED Display.brd, OLED Display.sch]
2023-12-20 Repanelizes the design now that it has vertical Qwiic connectors
    [OLED Display-Panel.brd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]

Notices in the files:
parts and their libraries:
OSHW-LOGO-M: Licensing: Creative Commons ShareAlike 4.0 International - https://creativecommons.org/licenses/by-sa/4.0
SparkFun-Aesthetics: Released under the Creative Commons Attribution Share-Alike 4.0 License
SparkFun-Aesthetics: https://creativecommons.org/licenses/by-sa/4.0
